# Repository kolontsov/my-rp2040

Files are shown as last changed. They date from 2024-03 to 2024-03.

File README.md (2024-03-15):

# My-RP2040

A small [RP2040](https://datasheets.raspberrypi.com/rp2040/rp2040-datasheet.pdf) board, with USB-C, 8MB of flash, SWD interface, 22 GPIO, and a LED. Size: 24x37mm.

This board serves no special purpose other than being an exercise in designing an RP2040 board.

- Designed in KiCad 8, manufactured and assembled at [JLCPCB](https://jlcpcb.com/), confirmed to work.
- Follows recommendation from the [Hardware design with RP2040](https://datasheets.raspberrypi.com/rp2040/hardware-design-with-rp2040.pdf).
- Some footprints and 3D models are from my [personal library](https://github.com/kolontsov/kicad-lib).
- Uses [design rules](https://github.com/labtroll/KiCad-DesignRules) to match JLCPCB [capabilities](https://jlcpcb.com/capabilities/pcb-capabilities).
- Production files (Gerbers, BOM, and CPL) are generated with the help of the [KiCad JLCPCB plugin](https://github.com/Bouni/kicad-jlcpcb-tools).

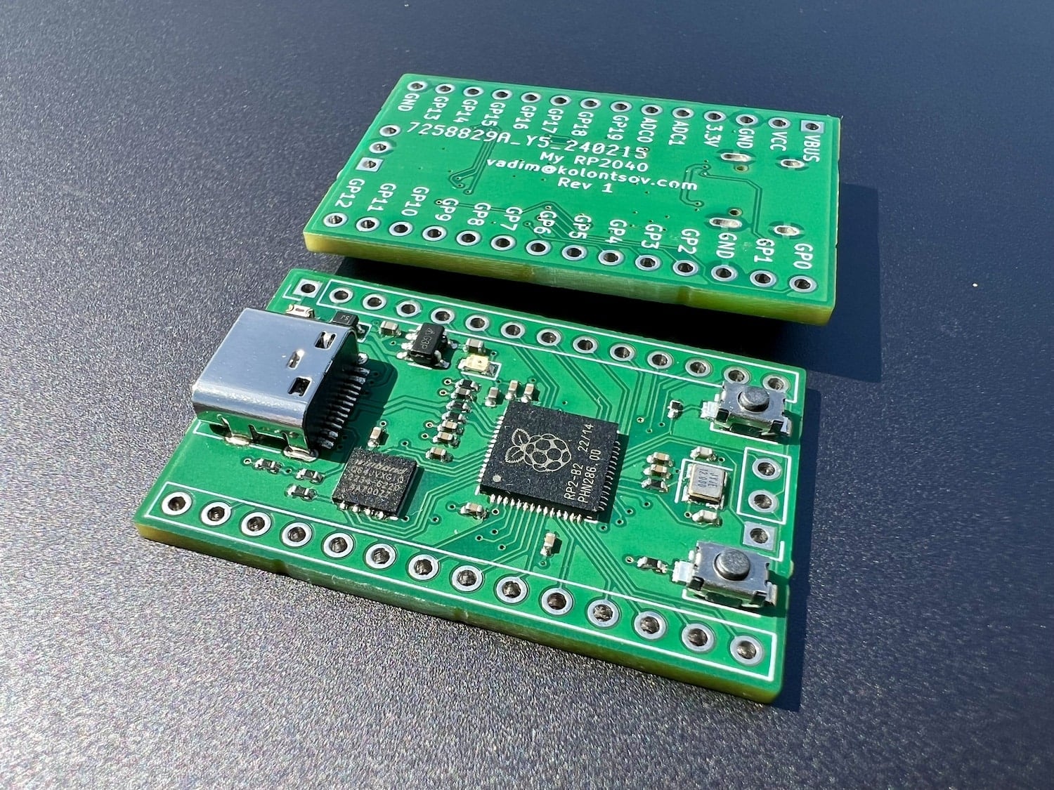
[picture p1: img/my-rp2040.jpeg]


## Pinout

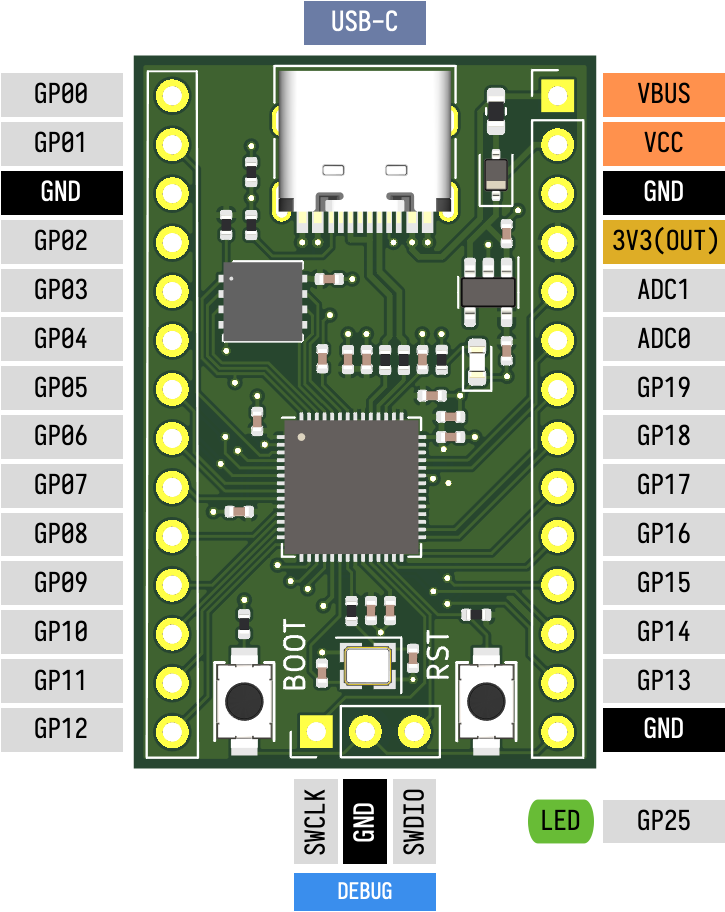
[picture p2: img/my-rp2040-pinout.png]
RP2040 pinout


## License

Creative Commons (CC0-1.0). For the license text, see [LICENSE](LICENSE).

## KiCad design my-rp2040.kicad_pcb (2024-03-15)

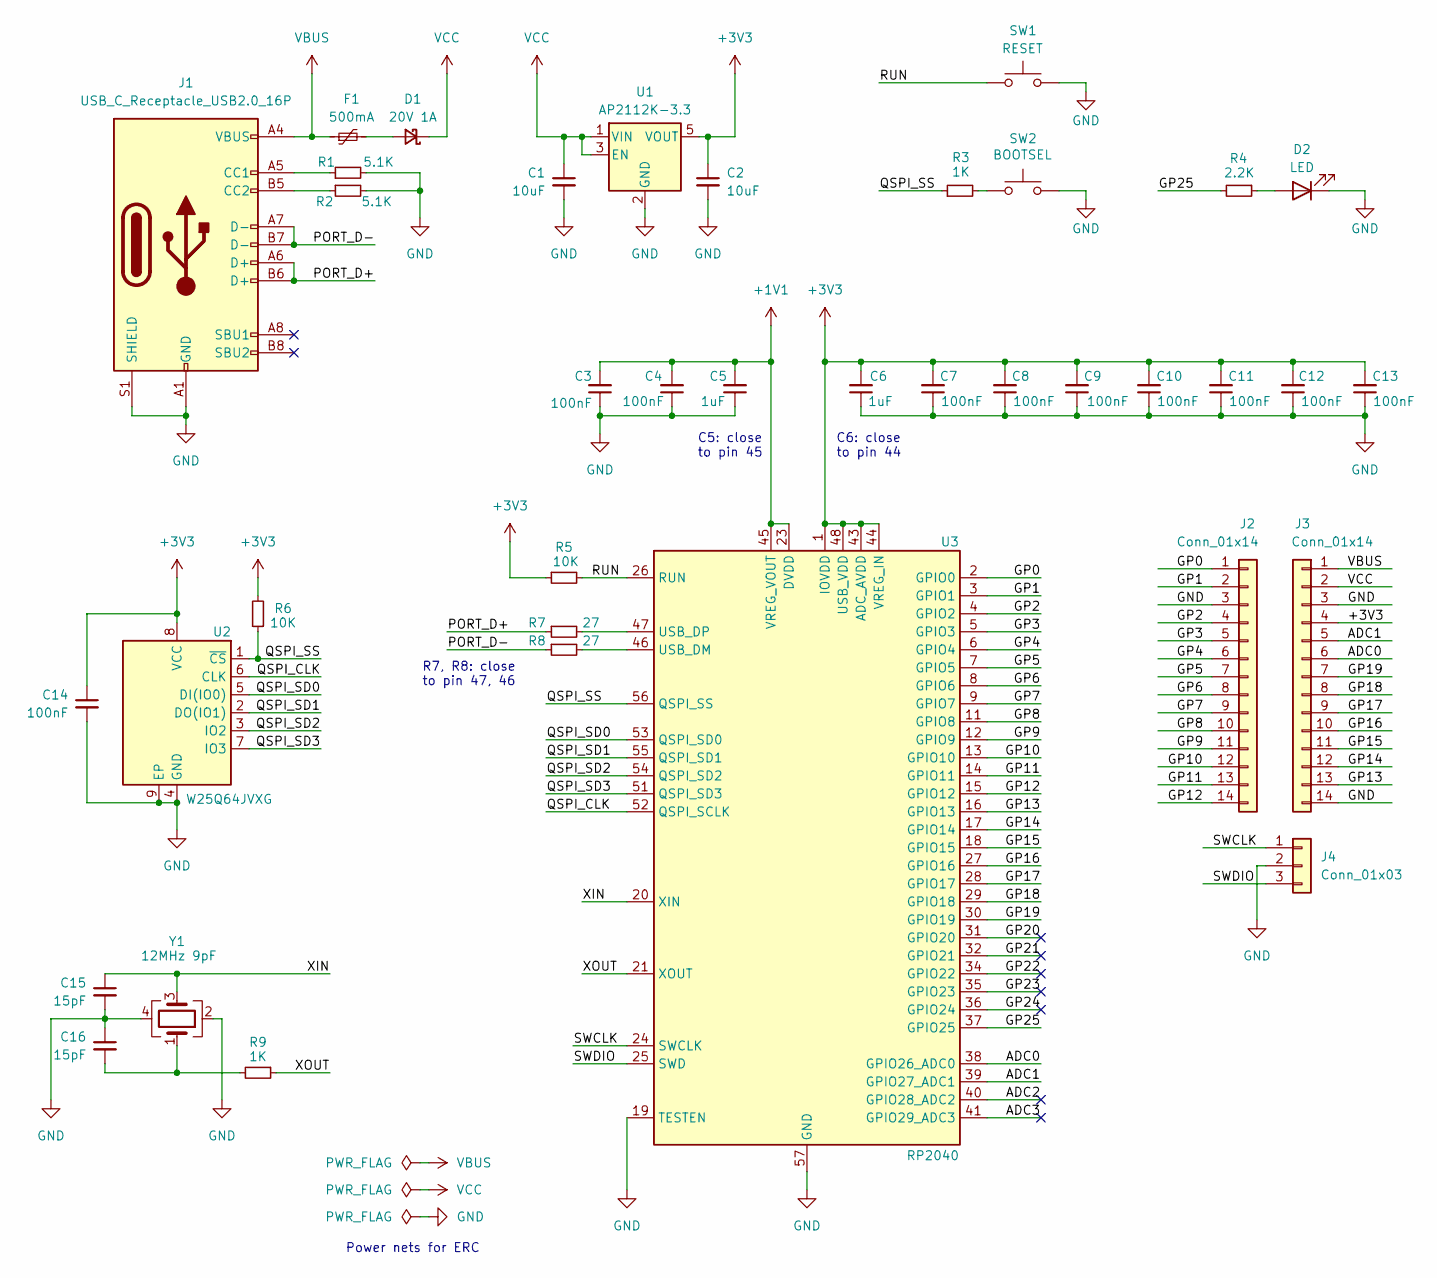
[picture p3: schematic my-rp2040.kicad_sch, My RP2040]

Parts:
C1, C2: 10uF; C_0402_1005Metric; MPN CL05A106MQ5NUNC; LCSC C15525
C3, C4, C7, C8, C9, C10, C11, C12, C13, C14: 100nF; C_0402_1005Metric; MPN CL05B104KO5NNNC; LCSC C1525
C5, C6: 1uF; C_0402_1005Metric; MPN CL05A105KA5NQNC; LCSC C52923
C15, C16: 15pF; C_0402_1005Metric; MPN 0402CG150J500NT; LCSC C1548
D1: 20V 1A; D_SOD-323; MPN B5817WS; LCSC C123899
D2: LED; LED_0603_1608Metric; MPN 19-213/Y2C-CQ2R2L/3T(CY); LCSC C72038
F1: 500mA; Fuse_0603_1608Metric; MPN MF-FSMF050X-2; LCSC C210357
J1: USB_C_Receptacle_USB2.0_16P; USB_C_Receptacle_HRO_TYPE-C-31-M-12; MPN TYPE-C-31-M-12; LCSC C165948
J2, J3: Conn_01x14; PinHeader_1x14_P2.54mm_Vertical
J4: Conn_01x03; PinHeader_1x03_P2.54mm_Vertical
R1, R2: 5.1K; R_0402_1005Metric; MPN 0402WGF5101TCE; LCSC C25905
R3, R9: 1K; R_0402_1005Metric; MPN 0402WGF1001TCE; LCSC C11702
R4: 2.2K; R_0402_1005Metric; MPN 0402WGF2201TCE; LCSC C25879
R5, R6: 10K; R_0402_1005Metric; MPN 0402WGF1002TCE; LCSC C25744
R7, R8: 27; R_0402_1005Metric; MPN 0402WGF270JTCE; LCSC C25100
SW1: RESET; SW-SMD-TS-1088-AR02016; MPN TS-1088-AR02016; LCSC C720477
SW2: BOOTSEL; SW-SMD-TS-1088-AR02016; MPN TS-1088-AR02016; LCSC C720477
U1: AP2112K-3.3; SOT-23-5; MPN AP2112K-3.3TRG1; LCSC C51118
U2: W25Q64JVXG; XSON-8_L4.0-W4.0-P0.80-TL-EP; MPN W25Q64JVXGIQ; LCSC C2940195
U3: RP2040; QFN-56-1EP_7x7mm_P0.4mm_EP3.2x3.2mm; MPN RP2040; LCSC C2040
Y1: 12MHz 9pF; Crystal_SMD_2520-4Pin_2.5x2.0mm; MPN 2TJ412000HYGBC; LCSC C2149204

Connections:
+1V1: C3.2, C4.2, C5.2, U3.23 (DVDD), U3.45 (VREG_VOUT), U3.50 (DVDD)
+3V3: C2.1, C6.2, C7.2, C8.2, C9.2, C10.2, C11.2, C12.2, C13.2, C14.1, J3.4, R5.1, R6.2, U1.5 (VOUT), U2.8 (VCC), U3.1 (IOVDD), U3.10 (IOVDD), U3.22 (IOVDD), U3.33 (IOVDD), U3.42 (IOVDD), U3.43 (ADC_AVDD), U3.44 (VREG_IN), U3.48 (USB_VDD), U3.49 (IOVDD)
/ADC0: J3.6, U3.38 (GPIO26_ADC0)
/ADC1: J3.5, U3.39 (GPIO27_ADC1)
/ADC2: U3.40 (GPIO28_ADC2)
/ADC3: U3.41 (GPIO29_ADC3)
/GP0: J2.1, U3.2 (GPIO0)
/GP1: J2.2, U3.3 (GPIO1)
/GP2: J2.4, U3.4 (GPIO2)
/GP3: J2.5, U3.5 (GPIO3)
/GP4: J2.6, U3.6 (GPIO4)
/GP5: J2.7, U3.7 (GPIO5)
/GP6: J2.8, U3.8 (GPIO6)
/GP7: J2.9, U3.9 (GPIO7)
/GP8: J2.10, U3.11 (GPIO8)
/GP9: J2.11, U3.12 (GPIO9)
/GP10: J2.12, U3.13 (GPIO10)
/GP11: J2.13, U3.14 (GPIO11)
/GP12: J2.14, U3.15 (GPIO12)
/GP13: J3.13, U3.16 (GPIO13)
/GP14: J3.12, U3.17 (GPIO14)
/GP15: J3.11, U3.18 (GPIO15)
/GP16: J3.10, U3.27 (GPIO16)
/GP17: J3.9, U3.28 (GPIO17)
/GP18: J3.8, U3.29 (GPIO18)
/GP19: J3.7, U3.30 (GPIO19)
/GP20: U3.31 (GPIO20)
/GP21: U3.32 (GPIO21)
/GP22: U3.34 (GPIO22)
/GP23: U3.35 (GPIO23)
/GP24: U3.36 (GPIO24)
/GP25: R4.2, U3.37 (GPIO25)
/PORT_D+: J1.A6 (D+), J1.B6 (D+), R7.1
/PORT_D-: J1.A7 (D-), J1.B7 (D-), R8.1
/QSPI_CLK: U2.6 (CLK), U3.52 (QSPI_SCLK)
/QSPI_SD0: U2.5 (DI(IO0)), U3.53 (QSPI_SD0)
/QSPI_SD1: U2.2 (DO(IO1)), U3.55 (QSPI_SD1)
/QSPI_SD2: U2.3 (IO2), U3.54 (QSPI_SD2)
/QSPI_SD3: U2.7 (IO3), U3.51 (QSPI_SD3)
/QSPI_SS: R3.1, R6.1, U2.1 (~CS), U3.56 (QSPI_SS)
/RUN: R5.2, SW1.1, U3.26 (RUN)
/SWCLK: J4.1, U3.24 (SWCLK)
/SWDIO: J4.3, U3.25 (SWD)
/XIN: C15.1, U3.20 (XIN), Y1.3
/XOUT: R9.1, U3.21 (XOUT)
GND: C1.2, C2.2, C3.1, C4.1, C5.1, C6.1, C7.1, C8.1, C9.1, C10.1, C11.1, C12.1, C13.1, C14.2, C15.2, C16.1, D2.1 (K), J1.A1 (GND), J1.A12 (GND), J1.B1 (GND), J1.B12 (GND), J1.S1 (SHIELD), J2.3, J3.3, J3.14, J4.2, R1.2, R2.2, SW1.2, SW2.2, U1.2 (GND), U2.4 (GND), U2.9 (EP), U3.19 (TESTEN), U3.57 (GND), Y1.2, Y1.4
unnamed: C16.2, R9.2, Y1.1
unnamed: D1.2 (A), F1.2
unnamed: D2.2 (A), R4.1
unnamed: J1.A5 (CC1), R1.1
unnamed: J1.B5 (CC2), R2.1
unnamed: R3.2, SW2.1
unnamed: R8.2, U3.46 (USB_DM)
unnamed: R7.2, U3.47 (USB_DP)
VBUS: F1.1, J1.A4 (VBUS), J1.A9 (VBUS), J1.B4 (VBUS), J1.B9 (VBUS), J3.1
VCC: C1.1, D1.1 (K), J3.2, U1.1 (VIN), U1.3 (EN)

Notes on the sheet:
R7, R8: close to pin 47, 46
Power nets for ERC
C5: close to pin 45
C6: close to pin 44

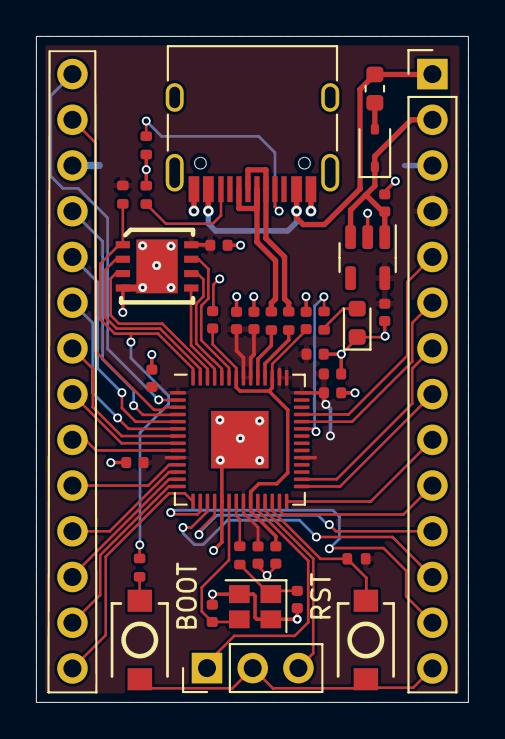
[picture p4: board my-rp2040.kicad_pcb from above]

Board: 2 copper layers, 24.0 x 37.0 mm, 38 parts (0 on the bottom side), 49 nets.
